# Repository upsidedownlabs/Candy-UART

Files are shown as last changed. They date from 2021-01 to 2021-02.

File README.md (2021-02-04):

# Candy UART



Candy size USB to UART bridge.

#### CH340C Candy

| Front |  Back |
| :---: | :---: |
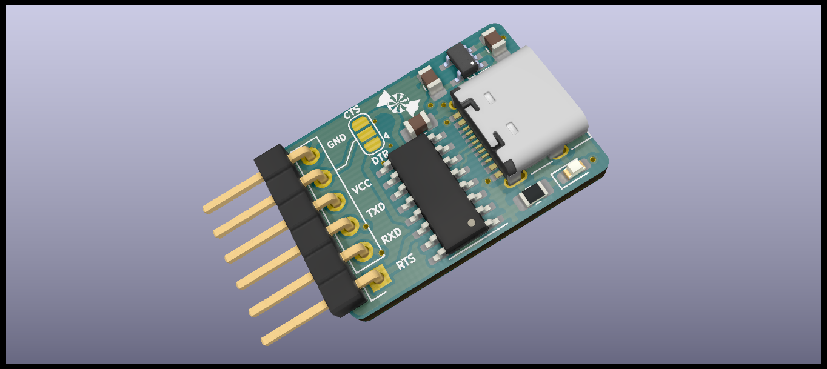
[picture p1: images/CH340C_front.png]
Upside Down Labs Candy UART - CH340C front
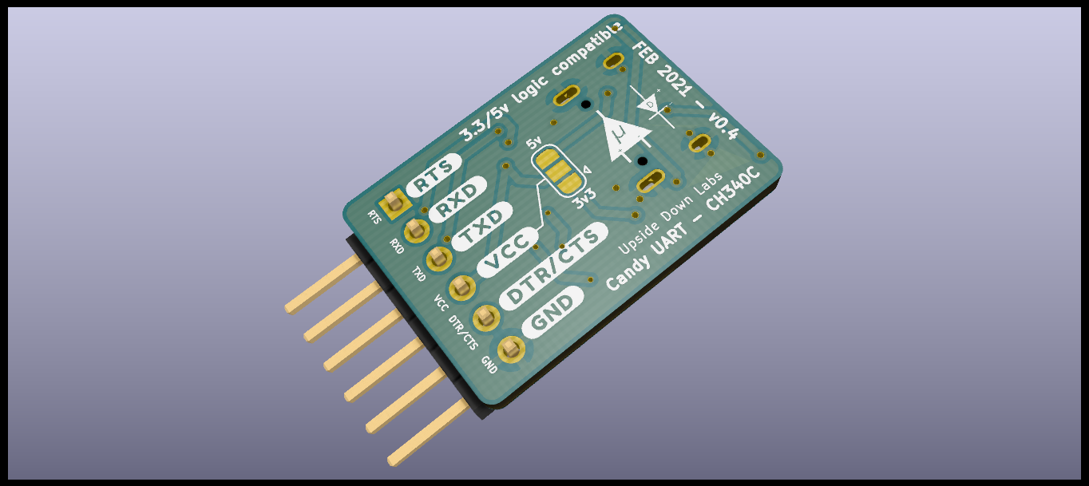
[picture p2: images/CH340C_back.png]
Upside Down Labs Candy UART - CH340C back
|   |  |

| Dimensions |  Schematic |
| :---: | :---: |
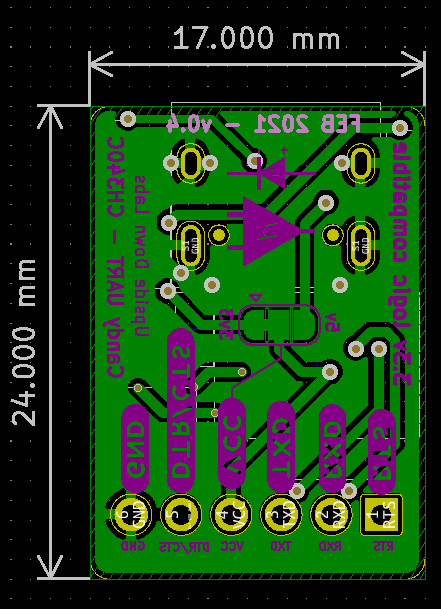
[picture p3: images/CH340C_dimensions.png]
Upside Down Labs Candy UART - CH340C dimensions
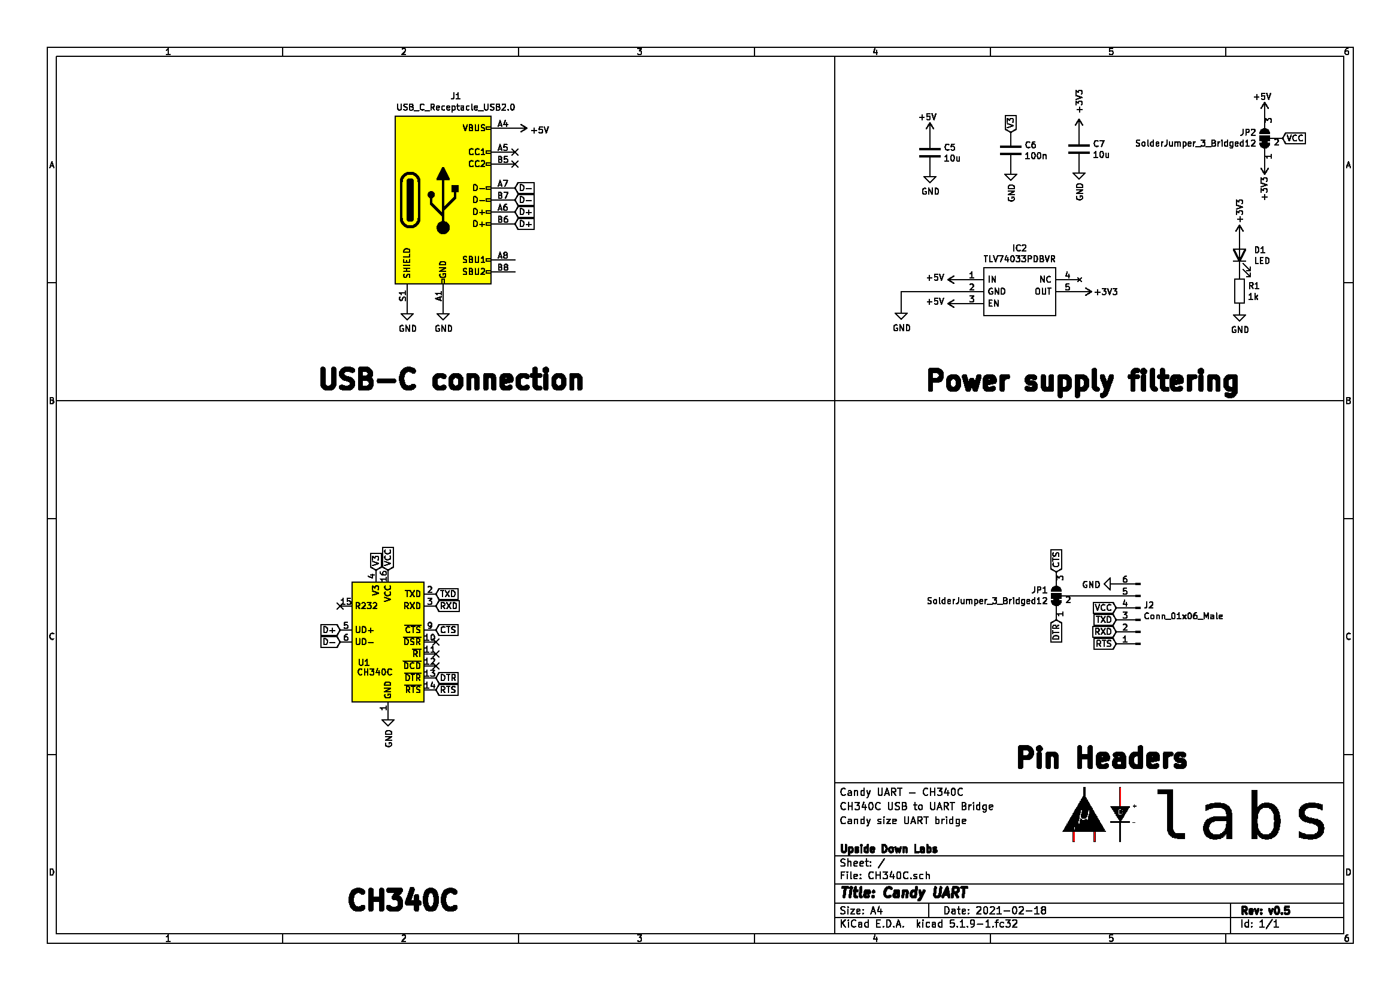
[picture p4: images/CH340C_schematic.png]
Upside Down Labs Candy UART - CH340C schematic
| 24.00 x 17.00 mm  |  |

#### FT232RQ Candy

| Front |  Back |
| :---: | :---: |
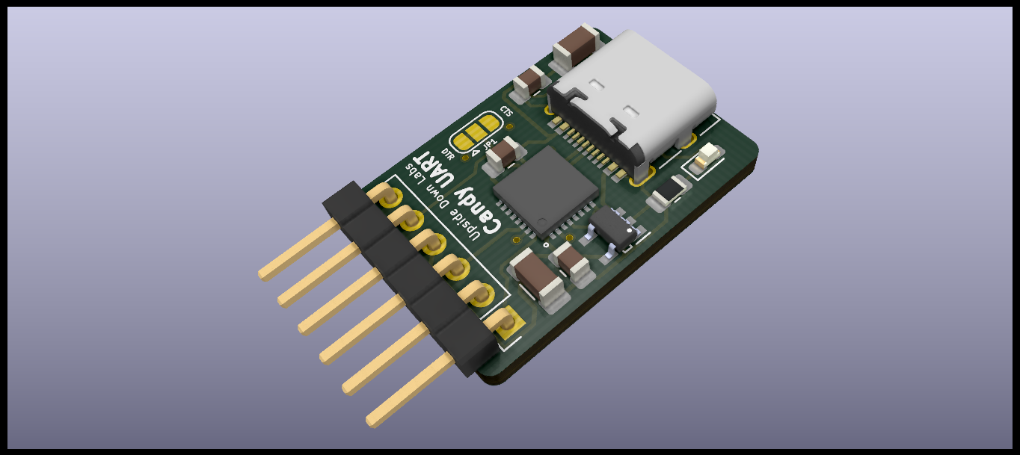
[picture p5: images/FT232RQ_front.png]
Upside Down Labs Candy UART - FT232RQ front
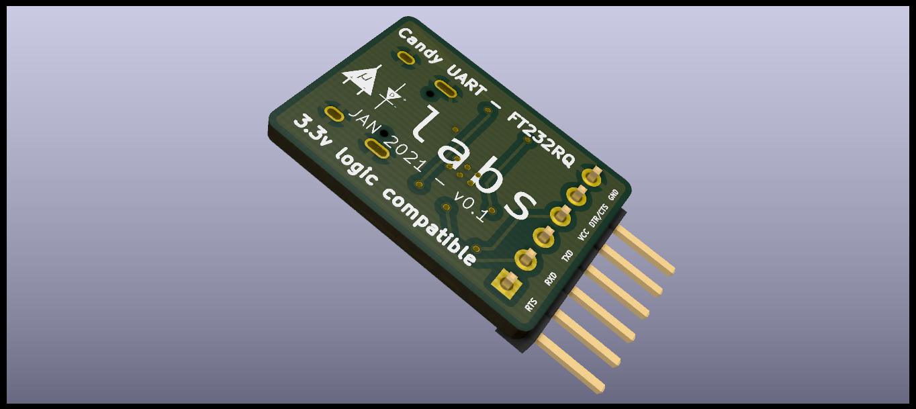
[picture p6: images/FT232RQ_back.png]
Upside Down Labs Candy UART - FT232RQ back
|   |  |

| Dimensions |  Schematic |
| :---: | :---: |
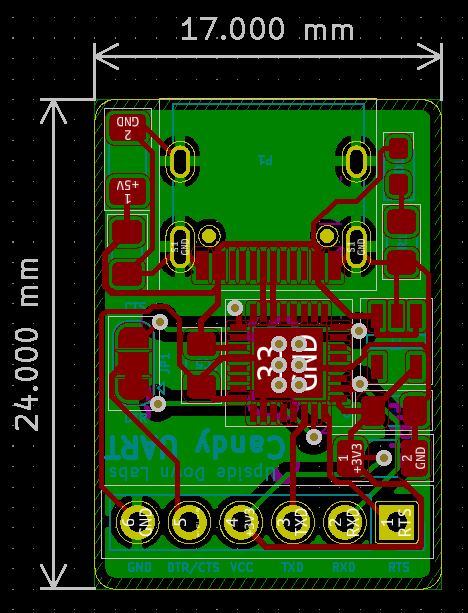
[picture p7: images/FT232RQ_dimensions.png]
Upside Down Labs Candy UART - FT232RQ dimensions
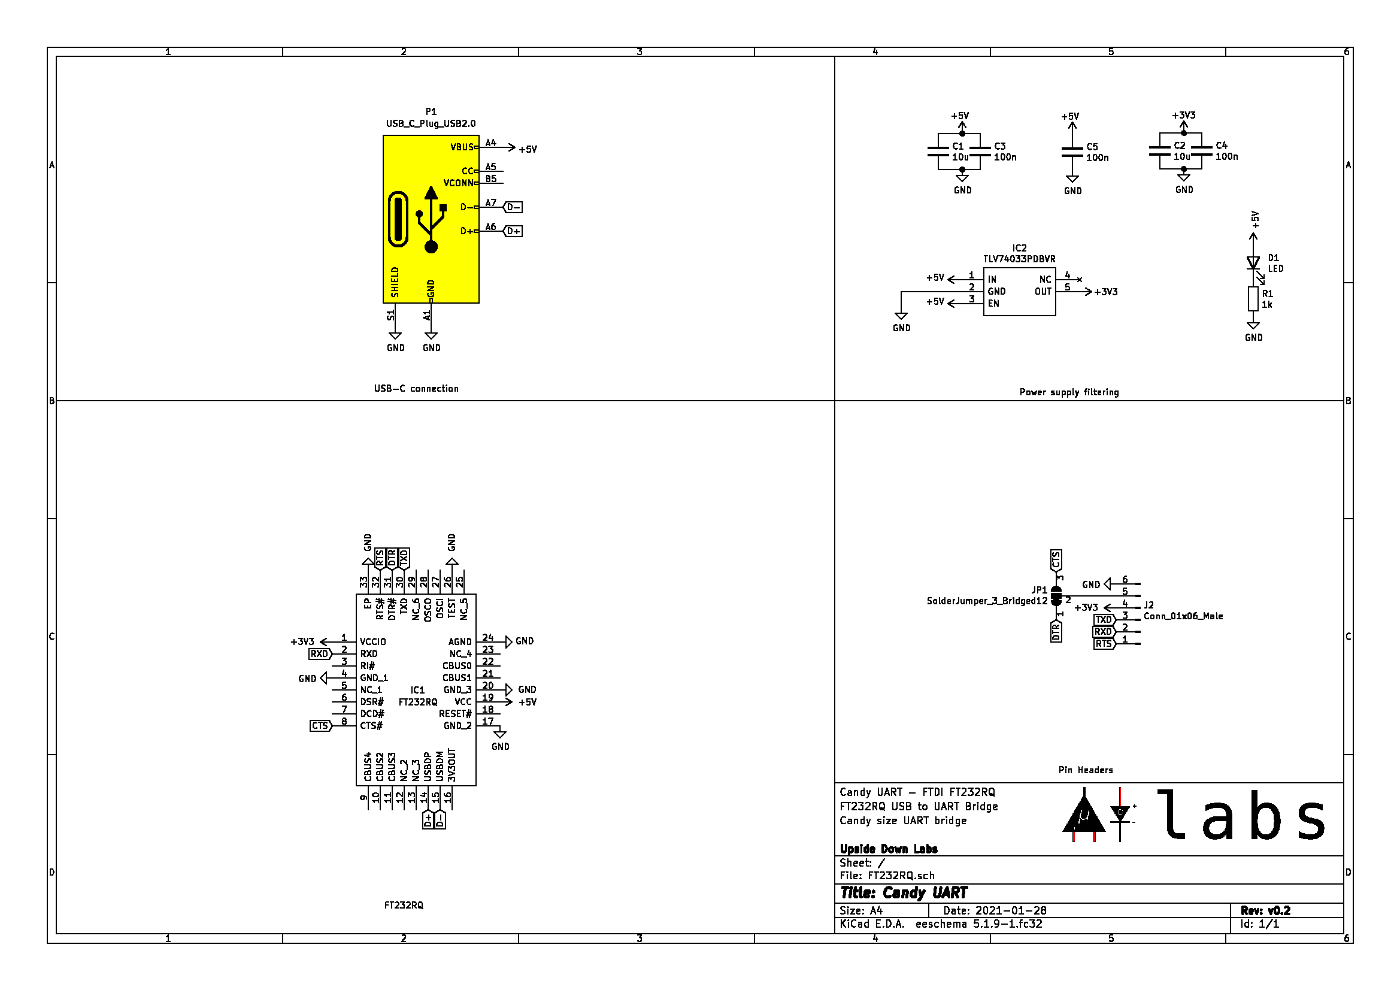
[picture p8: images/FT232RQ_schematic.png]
Upside Down Labs Candy UART - FT232RQ schematic
| 24.00 x 17.00 mm  |  |

## License
#### Hardware
CERN Open Hardware License Version 2 - Strongly Reciprocal ([CERN-OHL-S-2.0](https://spdx.org/licenses/CERN-OHL-S-2.0.html)).

#### Software
MIT open source [license](http://opensource.org/licenses/MIT).

#### Documentation:
<br />This work is licensed under a <a rel="license" href="http://creativecommons.org/licenses/by/4.0/">Creative Commons Attribution 4.0 International License</a>.

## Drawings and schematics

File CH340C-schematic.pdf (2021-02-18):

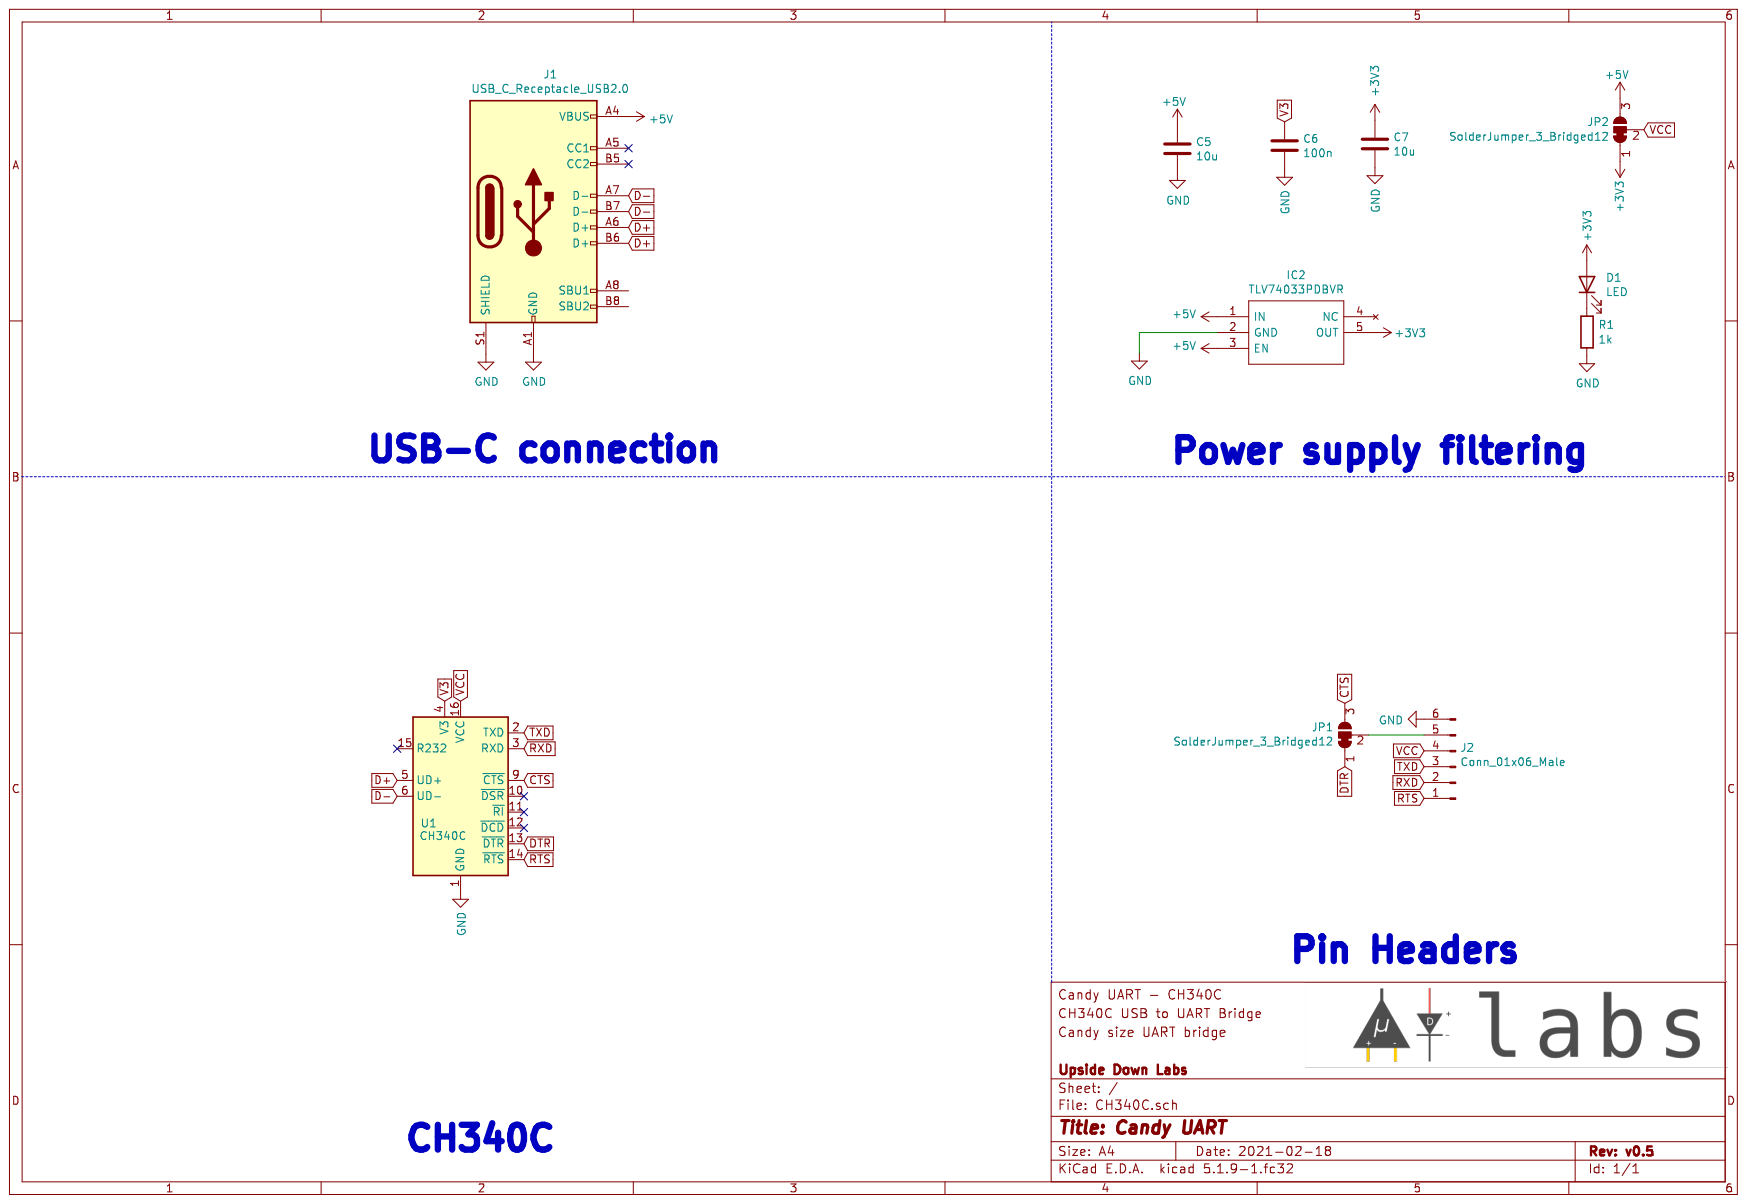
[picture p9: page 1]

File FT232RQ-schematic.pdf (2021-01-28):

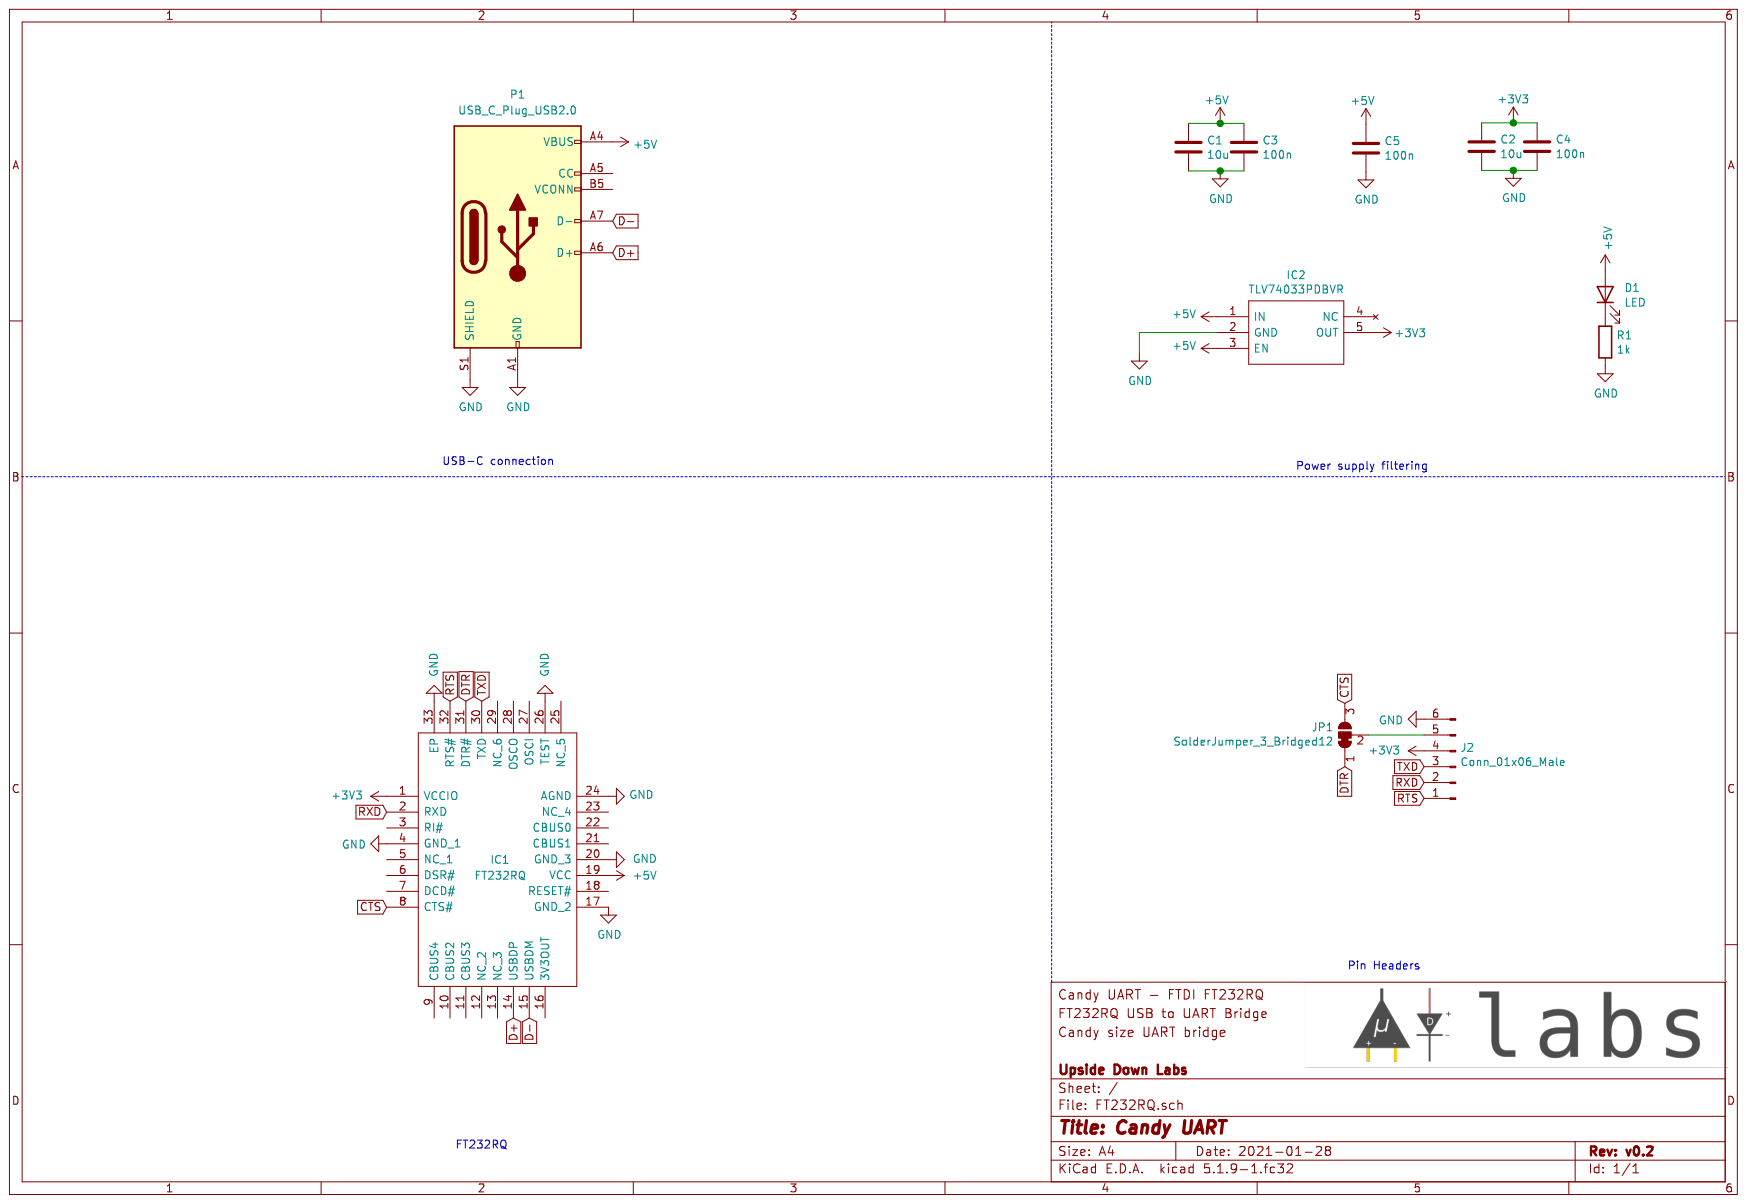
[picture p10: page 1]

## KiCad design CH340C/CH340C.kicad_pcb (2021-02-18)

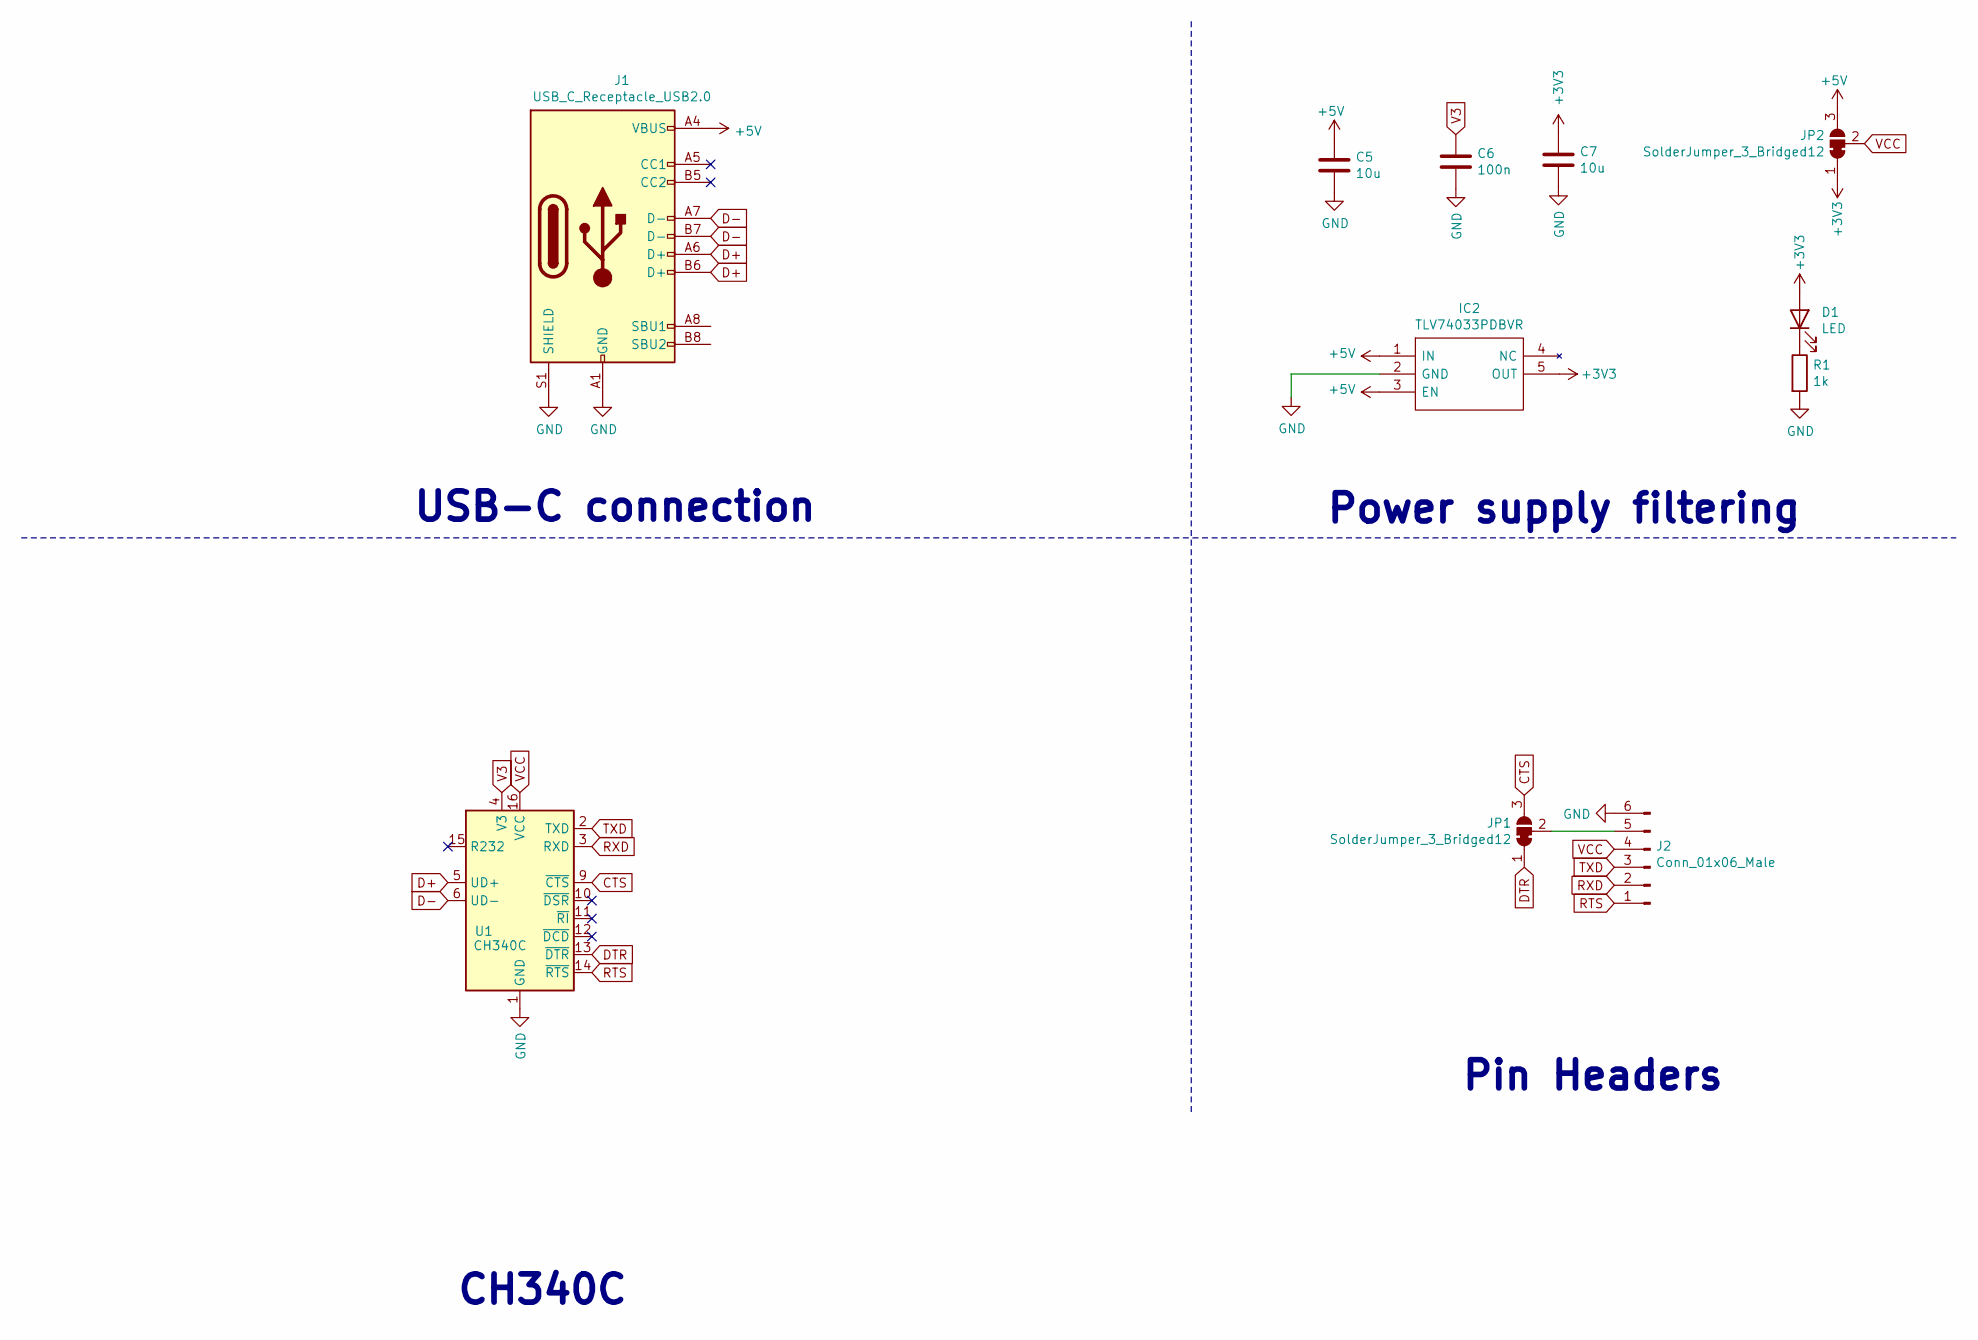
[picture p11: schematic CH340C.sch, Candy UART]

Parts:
C5, C7: 10u; C_0805_2012Metric_Pad1.18x1.45mm_HandSolder
C6: 100n; C_0805_2012Metric_Pad1.18x1.45mm_HandSolder
D1: LED; LED_0603_1608Metric_Pad1.05x0.95mm_HandSolder
IC2: TLV74033PDBVR; Manufacturer_Part_Number TLV74033PDBVR
J1: USB_C_Receptacle_USB2.0; USB_C_Receptacle_HRO_TYPE-C-31-M-12
J2: Conn_01x06_Male; PinSocket_1x06_P2.54mm_Vertical
JP1, JP2: SolderJumper_3_Bridged12; SolderJumper-3_P1.3mm_Bridged12_RoundedPad1.0x1.5mm
R1: 1k; R_0805_2012Metric_Pad1.20x1.40mm_HandSolder
U1: CH340C; SOIC-16_3.9x9.9mm_P1.27mm

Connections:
+3V3: C7.1, D1.2 (A), IC2.5 (OUT), JP2.1 (A)
+5V: C5.1, IC2.1 (IN), IC2.3 (EN), J1.A4 (VBUS), J1.A9 (VBUS), J1.B4 (VBUS), J1.B9 (VBUS), JP2.3 (B)
CTS: JP1.3 (B), U1.9 (~CTS)
D+: J1.A6 (D+), J1.B6 (D+), U1.5 (UD+)
D-: J1.A7 (D-), J1.B7 (D-), U1.6 (UD-)
DTR: JP1.1 (A), U1.13 (~DTR)
GND: C5.2, C6.2, C7.2, IC2.2 (GND), J1.A1 (GND), J1.A12 (GND), J1.B1 (GND), J1.B12 (GND), J1.S1 (SHIELD), J2.6, R1.2, U1.1 (GND)
unnamed: D1.1 (K), R1.1
unnamed: J2.5, JP1.2 (C)
RTS: J2.1, U1.14 (~RTS)
RXD: J2.2, U1.3 (RXD)
TXD: J2.3, U1.2 (TXD)
V3: C6.1, U1.4 (V3)
VCC: J2.4, JP2.2 (C), U1.16 (VCC)

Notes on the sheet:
Power supply filtering
USB-C connection
CH340C
Pin Headers

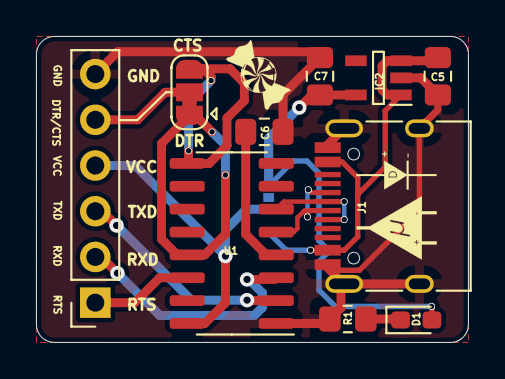
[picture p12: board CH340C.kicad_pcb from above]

Board: 2 copper layers, 24.0 x 17.0 mm, 11 parts (1 on the bottom side), 14 nets.

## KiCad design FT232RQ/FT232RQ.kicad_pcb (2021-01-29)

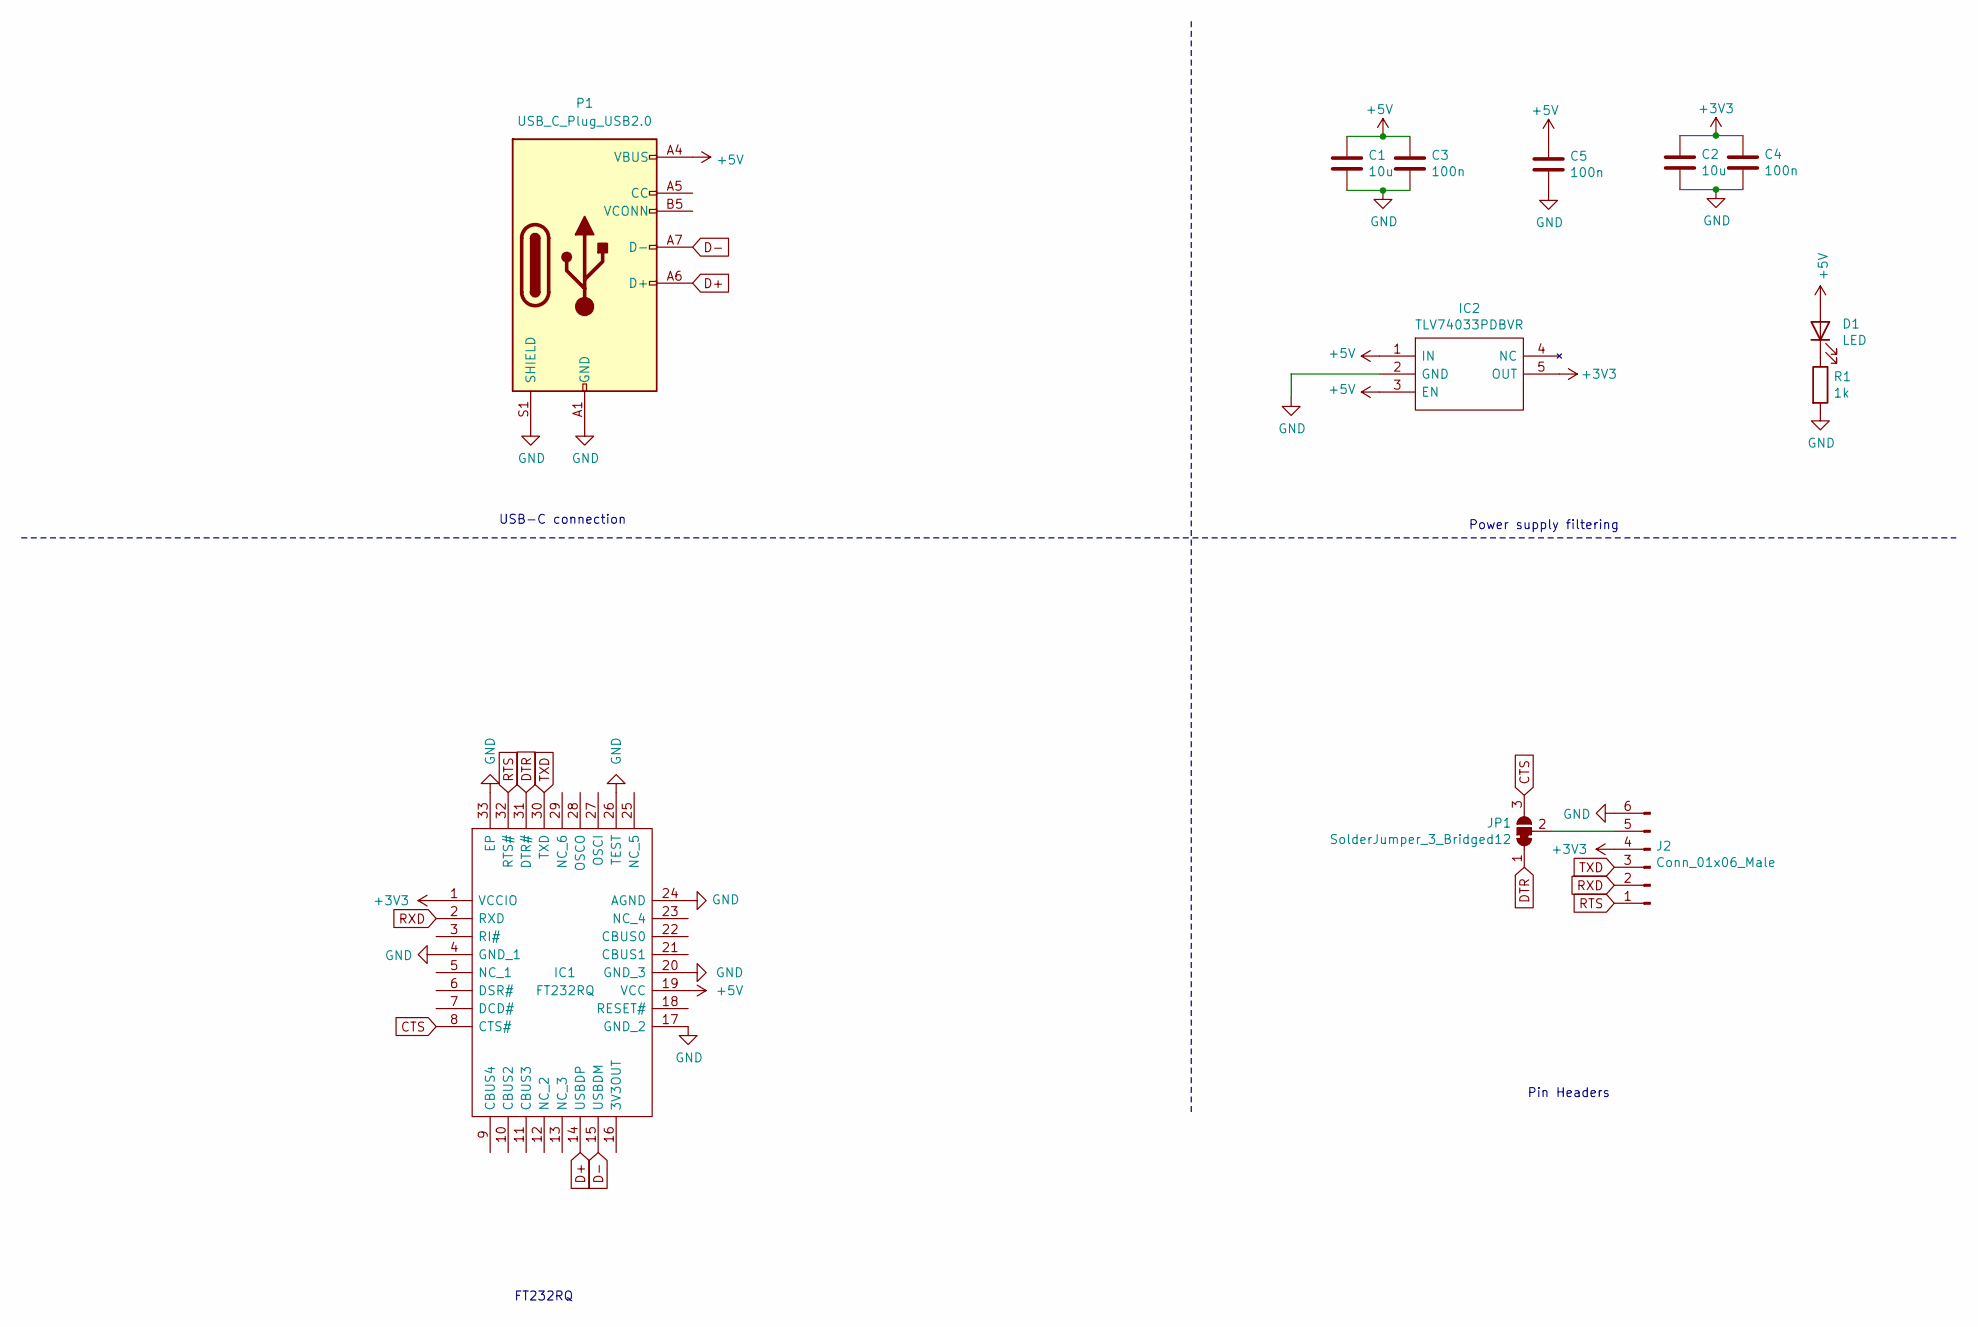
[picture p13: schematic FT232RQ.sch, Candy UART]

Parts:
C1, C2: 10u; C_1206_3216Metric_Pad1.33x1.80mm_HandSolder
C3, C4, C5: 100n; C_0805_2012Metric_Pad1.18x1.45mm_HandSolder
D1: LED; LED_0603_1608Metric_Pad1.05x0.95mm_HandSolder
IC1: FT232RQ; Manufacturer_Part_Number FT232RQ; Mouser Part Number 895-FT232RQ
IC2: TLV74033PDBVR; Manufacturer_Part_Number TLV74033PDBVR
J2: Conn_01x06_Male; PinSocket_1x06_P2.54mm_Vertical
JP1: SolderJumper_3_Bridged12; SolderJumper-3_P1.3mm_Bridged12_RoundedPad1.0x1.5mm
P1: USB_C_Plug_USB2.0; USB_C_Receptacle_HRO_TYPE-C-31-M-12
R1: 1k; R_0805_2012Metric_Pad1.20x1.40mm_HandSolder

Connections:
+3V3: C2.1, C4.1, IC1.1 (VCCIO), IC2.5 (OUT), J2.4
+5V: C1.1, C3.1, C5.1, D1.2 (A), IC1.19 (VCC), IC2.1 (IN), IC2.3 (EN), P1.A4 (VBUS), P1.A9 (VBUS), P1.B4 (VBUS), P1.B9 (VBUS)
CTS: IC1.8 (CTS#), JP1.3 (B)
D+: IC1.14 (USBDP), P1.A6 (D+)
D-: IC1.15 (USBDM), P1.A7 (D-)
DTR: IC1.31 (DTR#), JP1.1 (A)
GND: C1.2, C2.2, C3.2, C4.2, C5.2, IC1.4 (GND_1), IC1.17 (GND_2), IC1.20 (GND_3), IC1.24 (AGND), IC1.26 (TEST), IC1.33 (EP), IC2.2 (GND), J2.6, P1.A1 (GND), P1.A12 (GND), P1.B1 (GND), P1.B12 (GND), P1.S1 (SHIELD), R1.2
unnamed: D1.1 (K), R1.1
unnamed: J2.5, JP1.2 (C)
RTS: IC1.32 (RTS#), J2.1
RXD: IC1.2 (RXD), J2.2
TXD: IC1.30 (TXD), J2.3

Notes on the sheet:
Power supply filtering
USB-C connection
FT232RQ
Pin Headers

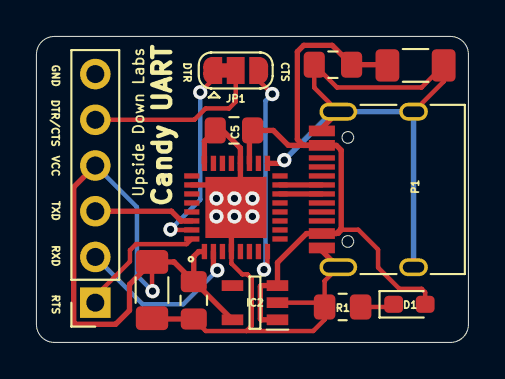
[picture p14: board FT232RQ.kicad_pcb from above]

Board: 2 copper layers, 24.0 x 17.0 mm, 12 parts (0 on the bottom side), 12 nets.

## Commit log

2021-01-28 Add KiCAD files
    KiCAD files for Candy UART (FT232RQ variant).
    [FT232RQ.kicad_pcb, FT232RQ.sch]
2021-01-28 add FT232RQ schematic
    Schematic for FT232RQ based Candy UART board from Upside Down Labs.
2021-01-28 add FT232RQ back image
    Rendered back image of FT232RQ based Candy UART board.
2021-01-28 add FT232RQ front image
    Rendered front image of FT232RQ based Candy UART board.
2021-01-28 add FT232RQ dimensions image
    Rendered dimensions image of FT232RQ based Candy UART board.
2021-01-28 update FT232RQ back image
    The normal image replaced with image captured with raytracing feature of KiCAD.
2021-01-29 update PCB
    tracks has been rerouted to make sure nobody cuts when manipulating the solder joint.
    [FT232RQ.kicad_pcb]
2021-01-30 add FT232RQ schematic image
2021-02-04 Add Ch340C candy
    [CH340C.kicad_pcb, CH340C.sch]
2021-02-04 add Ch340C candy schematic image
2021-02-04 rotate FT232RQ candy schematic image
2021-02-04 add CH340C schematic pdf
2021-02-04 Update to v0.4
    [CH340C.kicad_pcb, CH340C.sch]
2021-02-04 update to CH340C v0.4 schematic
2021-02-18 update to v0.5
    [CH340C.kicad_pcb, CH340C.sch]
2021-02-18 Update CH340C schematic pdf
2021-02-18 Update CH340C schematic
